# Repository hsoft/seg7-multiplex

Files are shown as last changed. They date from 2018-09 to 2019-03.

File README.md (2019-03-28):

# Multiplexed 7-segment display array

This board is a multiplexed array of 4 7-segment displays that receives its
input through a custom serial protocol. The board uses a USB-A connector to
connect `VCC`, `GND` and its two serial pins. It's multiplexed to minimize the
number of pins and ICs we need to use. We end up only needing an ATtiny45 and
2 ICs to drive the 4 displays.

The goal is to be able to offload the "digit display" complexity off little
devices I'm planning to do. Of course, there's tons of ready-to-use displays
out there but I'd like to explore simple and minimal designs.

I'm also hoping to have something that draws minimal current. My current
prototype (v3) works on 3V and draws about 7mA when it's not receiving data. For
reference, the backlight of a typical 2x8 LCD screen draws something like
20-40mA.

Click on the image below for a video:

vimeo (https://vimeo.com/327108521)

## Serial protocol

It works by serially sending it 5 bits of data using `INSER` and `INCLK`, the
first 4 bits being an encoded digit from `0` to `9`. Each digit is sent
starting with the most significant bit. Before each digit, a single bit is sent
to indicate whether this digit has a dot. The first digit to be sent is the
least significant digit (the rightmost).

Before that, a single "empty" clock is sent to "wake" the MCU up and give it
time to put itself in "input" mode (that is, give it time to finish its current
refresh operation, if any).

The driver should wait 200us before the "wake up" trigger and the rest of the
data so that we have time to finish any ongoing display refresh operation.
after that, 50us between each clock should be enough.

Thus, to send "43.21", the bits to be sent would be:

    00100 (4)
    10011 (dot + 3)
    00010 (2)
    00001 (1)
    01010 (10, the checksum of 4 + 3 + 2 + 1)

This is done for each digit that needs to be shown (starting with the rightmost
digit). This means 20 bits.

Following that, we have a checksum which is the sum, in binary form, of the
sent digits. That sum is 5 bits long. It's not enough to hold the maximum value
(36) of that sum, but being 5 bits simplifies the code and is solid enough for
our purpose. Dot masks aren't checksummed.

If the checksum doesn't match the received number, the display shows an error
that can't be mistaken for a real number.

I could have gone for sending straight binary values instead of digits but I
thought it would be nice to eventually add support for special values (dash,
empty, etc)

The board itself takes care of properly refreshing the displays. We refresh one
display every 1ms, cycling over active displays. We only need to send new digits
when they change.

## Prototypes

### v1

My first prototype was using two shift registers to multiplex my 7-segments
digits. It worked rather well but my craftmanship was lacking. Soldering wasn't
good and the board was too cramped. I also forgot (or didn't know about) to add
decoupling capacitors next to my ICs and I think that this is why that prototype
wasn't working perfectly (it would receive the wrong data through serial and
would even sometimes have a corrupt display (missing/extra segment) about 10% of
the time). Also, to get that figure to 10% from 50%, I had to lower my serial
clock timing to 100us (a minimum of 100us between serial clocks). That seems a
bit high to me. Something is fishy.

As a software developer, I'm used to be on solid grounds. If the code is
logical, generally, things work. Here I have to learn to deal with timing and
power fluctuation issues. These present interesting challenges.

Because my board was too cramped, I needed to make a new prototype altogether
(with decoupling capacitors this time) and I thought that if I was going to do
that, I might as well try another design, that is, my v2.

You can see the code for this v1 in the `v1` branch of this repo. I have no
KiCAD schema though. Never bothered. Will do for v2 though.

### v2

Although I think that my design for v1 was globally sound, I think in
retrospective that the MCU did too many things. The less things the MCU does,
the more logic you offload to ICs, the more robust your design is going to be (I
think). After all, people designing ICs went through much more trouble to make
sure it worked well than I did for my prototype...

So that's why I went with a new multiplex design with 3 ICs:

1. 7-segment decoder hooked to my displays
2. binary counter hooked to the decoder
3. shift register hooked to displays' `VCC` (and `DP`)

With the decoder + counter, sending a particular digit mask to the display is
only a matter of clocking the counter, so it's only two pin changes. That is
much much less than the number of pins we have to change to send a particular
digit mask into a shift register.

I could use a decade counter to only cycle through the first 10 glyphs of my
decoder's 16, but as I looked as extra glyphs, I realized (I really wasn't sure
what they were supposed to be for initially) that they're probably optimized for
multiplexing, that is, that the 5 extra masks (last one is blank) are masks that
"fit" multiple digits. For example, the 11th mask is the lower half of `5` which
also fits 6 and 8.

Therefore, when cycling through masks, you can enable `VCC` not only for exact
digit matches but also partial matches and, in the end, you've refreshed your
multiplexed displays properly. I'm thinking that 1ms per cycle should be good
enough to keep us under the 10ms threshold (at which point the eye starts to see
a flicker) even if we cycle through 16 digit masks.

One problem though is that the 7-segments decoder doesn't handle `DP`, which I'd
like to support. This is why I'm thinking of bringing down (theoretical) digit
support from 8 to 4 and hook 4 pins of my shift register directly to my `DP`
pins. This way, I'll handle `DP` status completely outside of the multiplexing
process.

With the `ATtiny45`, I only have 3 free output pins (2 pins are used for serial
communication). That requires creativity to handle all my ICs with only 3 pins,
but I think I have a good idea:

1. pins 1 and 2 hooked to my shift register
2. pin 3 to my binary counter
3. pin 3 also hooked to my shift register's `OE` pin (output enable).

I need to control `OE` because there's always going to be a slight window of
time during which the decoder cycled and the shift register hasn't updated `VCC`
pin yet. If I let `OE` on, then my displays are going to have "ghost" branches.
The pin clocking the binary counter is going to be in position to enable `OE`
most of the time and right when we will toggle the binary counter clock, `OE`
will become disabled. Then, I'll update the shift register and toggle `OE` back
(which will not trigger a binary counter update since it takes a full on/off
cycle to trigger). I haven't looked yet whether I'm going to be needing an
inverter for this. If yes, I'll probably look for a shift register that allows
me to do that without an inverter (an extra IC just for this seem a bit much).

**Conclusion**: It went well! It was the first time I ordered a PCB from a
KiCAD design. Of course, I made some mistakes in it and a lot of cowboy
soldering was necessary to adjust, but in the end, I had a fully functional
prototype! Unlike v1, it received data properly and displayed it correctly!

However, I'm not done yet, I need a v3 because 3 ICs is too many: I'd like to
get this package in a 55mmx30mmx20mm enclosure. I'll need to go "double side"
and remove an IC.

### v3

With v3, I get rid of the counter. Instead of using 4 bits of the SR for DP,
I connect them to the BCD. Then, I connect SER to DP add a refresh "round"
especially for DP. This means that we generally have to keep SER high to avoid
falsely lighting DPs.

It still offloads most of the complexity to the BCD and gets rid of an IC.
Moreover, althrough I didn't experience it, I felt that the CNT approach was
flaky: the counter **had** to stay in sync with the MCU and the MCU had no way
to reset the counter to enforce syncing (not enough pins).

## Build

To build the software, you need:

* [AVRA][avra]
* [avrdude][avrdude] to send firmware to MCUs

You can build the resulting `seg7multiplex.S.hex` with `make` and send it to
the MCU through `avrdude` with `make send`.

## Simulation

This project can be run on a desktop computer through [simavr][simavr]. It 
produces a VCD file which can then be opened with [gtkwave][gtkwave].

You can compile the simulation with `make simulation` and then run the
resulting executable without parameters.

The simulation runs two MCUs at the same time. First, of course, the
`seg7multiplex` program, but also, on a separate virtual attiny45, the `drive`
program. It hooks them up together and let them run for 2 seconds.

The resulting gtkwave file is very insightful for debugging.

[avra]: http://avra.sourceforge.net/
[avrdude]: https://www.nongnu.org/avrdude/
[simavr]: https://github.com/buserror/simavr
[gtkwave]: http://gtkwave.sourceforge.net/

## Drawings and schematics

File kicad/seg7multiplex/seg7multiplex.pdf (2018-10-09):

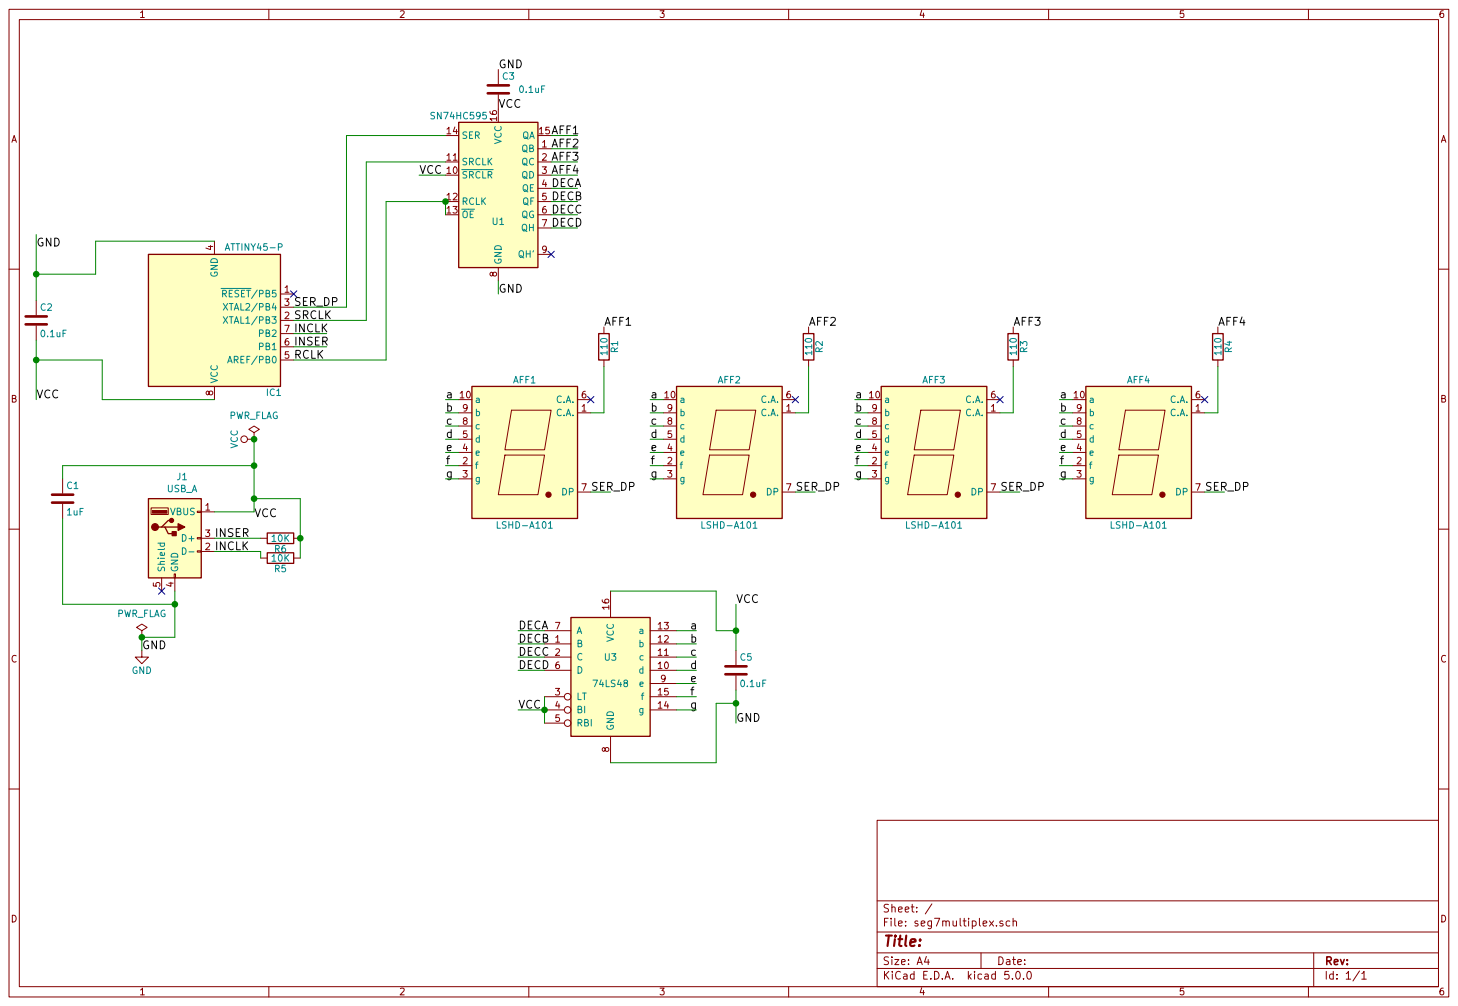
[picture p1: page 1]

INCLK
INSER

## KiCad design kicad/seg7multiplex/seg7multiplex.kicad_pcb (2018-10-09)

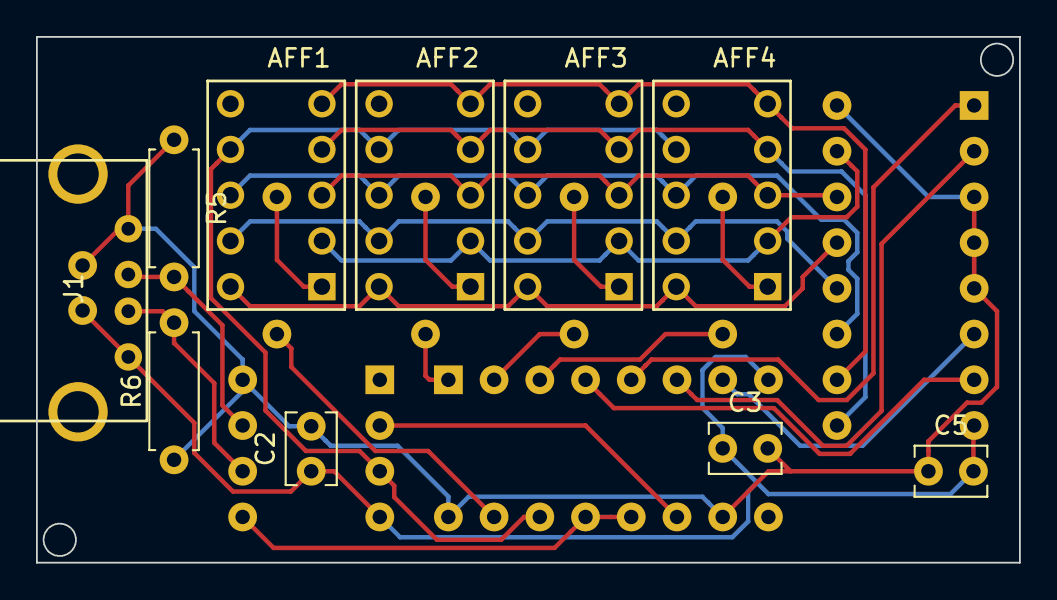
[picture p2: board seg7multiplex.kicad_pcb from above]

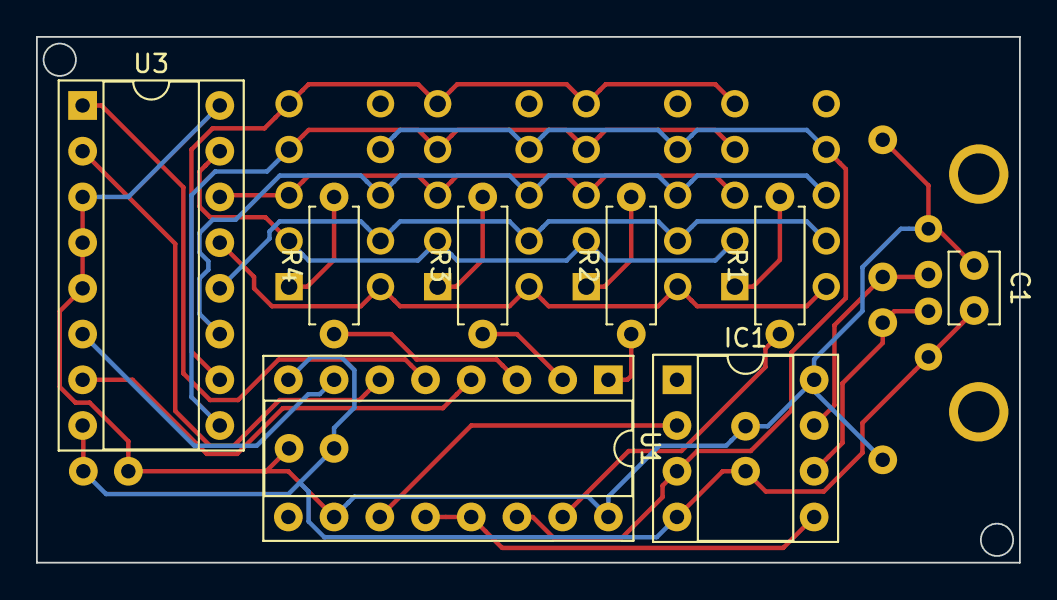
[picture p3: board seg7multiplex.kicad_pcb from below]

Board: 2 copper layers, 54.6 x 29.2 mm, 18 parts (8 on the bottom side), 26 nets.

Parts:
AFF1, AFF2, AFF3, AFF4: LSHD-A101
C1: 1uF; C_Disc_D3.8mm_W2.6mm_P2.50mm
C2, C3, C5: 0.1uF; C_Disc_D3.8mm_W2.6mm_P2.50mm
IC1: ATTINY45-P; DIP-8_W7.62mm_Socket
J1: USB_A; USB_A_Through
R1, R2, R3, R4: 110; R_Axial_DIN0207_L6.3mm_D2.5mm_P7.62mm_Horizontal
R5, R6: 10K; R_Axial_DIN0207_L6.3mm_D2.5mm_P7.62mm_Horizontal
U1: SN74HC595; DIP-16_W7.62mm_Socket
U3: 74LS48; DIP-16_W7.62mm_Socket

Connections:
/AFF1: R1.1, U1.15
/AFF2: R2.1, U1.1
/AFF3: R3.1, U1.2
/AFF4: R4.1, U1.3
/DECA: U1.4, U3.7
/DECB: U1.5, U3.1
/DECC: U1.6, U3.2
/DECD: U1.7, U3.6
/INCLK: IC1.7, J1.2, R5.2
/INSER: IC1.6, J1.3, R6.2
/RCLK: IC1.5, U1.12, U1.13
/SER_DP: AFF1.7, AFF2.7, AFF3.7, AFF4.7, IC1.3, U1.14
/SRCLK: IC1.2, U1.11
/a: AFF1.10, AFF2.10, AFF3.10, AFF4.10, U3.13
/b: AFF1.9, AFF2.9, AFF3.9, AFF4.9, U3.12
/c: AFF1.8, AFF2.8, AFF3.8, AFF4.8, U3.11
/d: AFF1.5, AFF2.5, AFF3.5, AFF4.5, U3.10
/e: AFF1.4, AFF2.4, AFF3.4, AFF4.4, U3.9
/f: AFF1.2, AFF2.2, AFF3.2, AFF4.2, U3.15
/g: AFF1.3, AFF2.3, AFF3.3, AFF4.3, U3.14
GND: C1.2, C2.1, C3.1, C5.2, IC1.4, J1.4, U1.8, U3.8
unnamed: AFF1.1, R1.2
unnamed: AFF2.1, R2.2
unnamed: AFF3.1, R3.2
unnamed: AFF4.1, R4.2
VCC: C1.1, C2.2, C3.2, C5.1, IC1.8, J1.1, R5.1, R6.1, U1.10, U1.16, U3.3, U3.4, U3.5, U3.16

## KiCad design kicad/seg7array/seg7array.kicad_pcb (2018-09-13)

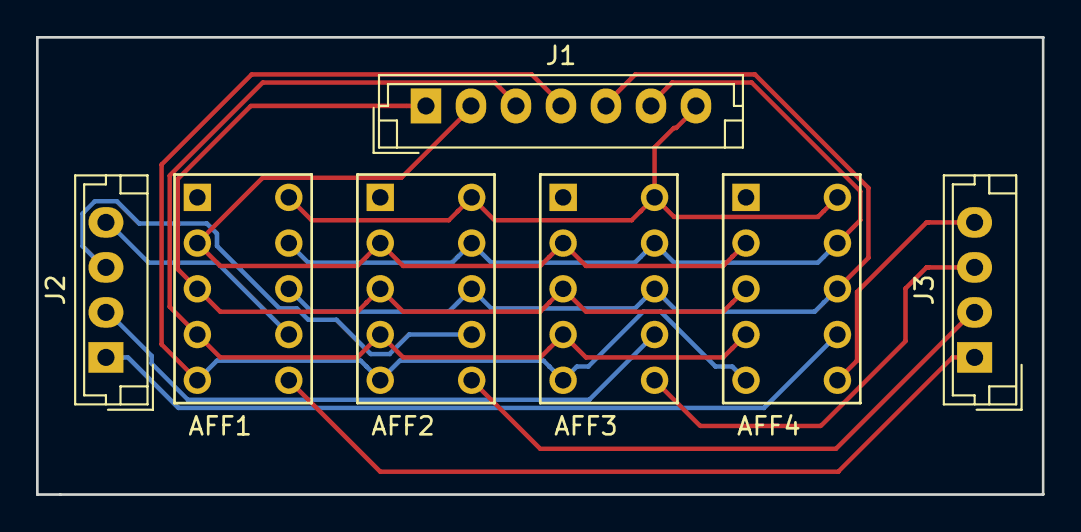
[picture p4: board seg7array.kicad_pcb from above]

Board: 2 copper layers, 55.9 x 25.4 mm, 7 parts (0 on the bottom side), 15 nets.

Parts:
AFF1, AFF2, AFF3, AFF4: LSHD-A101
J1: Conn_01x07; JST_EH_B07B-EH-A_1x07_P2.50mm_Vertical
J2, J3: Conn_01x04; JST_EH_B04B-EH-A_1x04_P2.50mm_Vertical

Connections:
/a: AFF1.10, AFF2.10, AFF3.10, AFF4.10, J1.7
/b: AFF1.9, AFF2.9, AFF3.9, AFF4.9, J1.6
/c: AFF1.8, AFF2.8, AFF3.8, AFF4.8, J1.5
/d: AFF1.5, AFF2.5, AFF3.5, AFF4.5, J1.4
/e: AFF1.4, AFF2.4, AFF3.4, AFF4.4, J1.3
/f: AFF1.2, AFF2.2, AFF3.2, AFF4.2, J1.2
/g: AFF1.3, AFF2.3, AFF3.3, AFF4.3, J1.1
unnamed: AFF1.6, J3.1
unnamed: AFF1.7, J2.4
unnamed: AFF2.6, J3.2
unnamed: AFF2.7, J2.3
unnamed: AFF3.6, J3.3
unnamed: AFF3.7, J2.2
unnamed: AFF4.6, J3.4
unnamed: AFF4.7, J2.1

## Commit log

2017-09-22 Fix glitches in seg7 simulation display
    It now works pretty well with our two displays. The only "glitch" we can
    see sometimes is the leftover of the previous digit when increasing our
    value, but that's to be expected because that's how the LED fading logic
    works.
2017-09-22 Add a 3rd digit through a decoder and inverter
    For a reason I haven't yet figured out, when we hit the `300` value, the
    LED display goes to `044`. strange...
2017-09-26 Stop using PB5
    Will I ever learn that this pin cannot be used as IO? To free that pin,
    I've made the `SER` pin shared between inputs and outputs. Works in
    simulation...
2017-10-24 Fix inverted B2 and B3 pins
    The wiring of the prototype wasn't the same as in the simulation. But as
    of now, we know that the "display" part of code works on the prototype (it
    has, however, only 3 digits)! The serial input hasn't been tested yet.
2017-10-30 sim: extract SerialInput from Circuit
    Also, use new `enable_interrupt_on_pin()` MCU method.
2017-11-04 Adapt code so it works with my new prototype
    I've scrapped my old prototype to make a new one that fits in a small
    box. The way wiring is done in this new prototype requires that I change
    my code.
    Also, add a new `--ftdi` option to the simulator!
2017-11-08 Big refactoring: make display refreshing routine more atomic
    My serial input routine was too heavy for its own good and I had to
    rethink the whole process. See comment in seg7multiplex.c
    This works in simulation, haven't tried on my prototype yet.
2017-11-10 Still trying to make things work
    My previous approach didn't work on the prototype, `SER` still got
    confused all the time. Now instead of having a fine-grained "lock" on
    `SER`'s input/output mode, I'm trying a more coarse-grained approach
    with `input_mode`.
    Here, we begin each serial session with a single "empty" `INCLK` rising
    edge that tells the MCU to stop all display refreshing activity. The MCU
    then sets `SER` to input mode as soon as it can in the runloop.
    On the other side of the serial wire, we have to wait a bit to make sure
    we're good to go, and then go ahead with or 20 bits (for 4 digits) of
    data.
    After that, the `input_mode` flag goes back to `false` and normal
    operations resu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
2017-11-10 Give INSER its own pin
    The idea of sharing the `SER` pin with `INSER` was a bad idea. It might
    be possible to make it work, but its over my current skill level.
    `SR1`'s `RCLK` had its own pin, so I took it out and hard-wired it to
    `SRCLK`. That makes the seg7 output code a bit uglier, but it frees a
    pin.
    This works on the prototype! finally!
    There are some occasional glitches though, but they're much much less
    frequent than ever before. I'll have to iron them out though...
2017-11-30 sim: extract circuit in a separate unit
    This will make integration in other projects easier.
2017-12-07 Add FTDI support to drive serial input of the real prototype!
    And it works! I have a functional prototype!
2018-03-15 Planning out v2 of my prototype
2018-03-19 Add KiCAD schema
    [seg7multiplex.sch]
2018-03-25 Update code and simulation to the v2 prototype
    Once a couple of kinks in `icemu` were fixed, works surprisely well,
    with serial input code untouched and all.
    `DP` is not implemented yet.
2018-09-07 Update to Kicad 5
    [seg7multiplex.sch]
2018-09-07 Try to associate some footprints to components
    [seg7multiplex.sch]
2018-09-08 Add USB connector to schema and generate netlist
    [seg7multiplex.sch]
2018-09-13 Add new kicad "seg7array" project
    [seg7array.kicad_pcb, seg7array.sch, seg7multiplex.sch]
2018-09-18 kicad: add seg7multiplex footprint
    [seg7multiplex.kicad_pcb, seg7multiplex.sch]
2018-10-08 Adjustment after first prototype revision
    I've received my first KiCAD-designed PCB! After a few cowboy adjustments
    (soldering stuff here and there), I could manage to make the thing work!
    But it flickered badly, so I had to heavily optimize my multiplexing
    algo to make flickering go away. As it is right now, and with
    modification to my KiCAD design (which have been done manually on my
    PCB to confirm soundness), I get a display that displays stuff correctly
    without flickering!
    I have yet to test the serial input. That's the next step before I send
    a second revision of the PCB to the fab.
    Exciting stuff!
    [seg7multiplex.kicad_pcb, seg7multiplex.sch]
2018-10-08 It works perfectly!!!
    After some sizeable messing around, I could finally make the prototype
    work perfrectly! I mean: the serial protocol works without a hitch, the
    proper digits get there 100% of the time! No flickering!
    One time cnosuming problem I had was that my FT232H controller I use
    for testing has a 5V power supply, but 3V logic (it outputs 3V to its
    data pins). It took me a while to realise that. Things weren't working
    at all.
    To make the prototype compatible with 3V logic, I transformed the
    pulldown resistors for INCLK and INSER into pull-up resistor so that the
    signal is brought a bit further from the 2.5V threshold between HIGH and
    LOW (it brings signal from 2.4V previously to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
    [seg7multiplex.kicad_pcb, seg7multiplex.sch]
2018-10-24 Reverse digits
    Bullseye! I received my PCB for this 3rd prototype, I solder it, power
    it up, it works perfectly on the first try! No flickering, displaying
    what it should... Except that the digits were reversed.
    I haven't tried USB communication yet though...
    So now I have this tight PCB that almost fits (U3 it too close to the
    screw socket, it doesn't fit quite right. But it's no big deal, I have
    wiggle room to move the IC a little bit away) in my small enclosure.
2019-01-15 Reverse digits (again)
    It seems that I've turned my displays around without noticing in my
    latest prototype.
    But otherwise, I now have a prototype that work very well! It properly
    receives input from FTDI, doesn't flicker and the board didn't need any
    modification!
    The only problem is that the board is a *tiny bit* too large on a corner
    to fit in my enclosure. I could cut the corner, but there's an IC there.
    There's enough place on the board to move it a bit, so I'll do that.
    But first, I need to test the communication protocol when it originates
    from another MCU (instead of a FTDI device).
2019-01-31 Merge digit_count into current_digit
    Since they're never used in the same mode, we can save one precious
    byte!
2019-01-31 Add checksum digit to communication protocol
    My prototype was sometimes (but rarely), receiving the wrong number. I'm
    not sure if it's due to bad soldering in my USB wire or voltage
    irregularities or whatever else, but if I'm going to use those readings
    for anything important, I have to be able to trust the the number
    displayed is the good one.
2019-02-20 sim: bring in the driver!
    First steps into allowing the simulation of a seg7 driver at the same
    time as the seg7 itself.
2019-02-22 Use AVRA for compiling instead of avr-gcc
    I like AVRA better than binutils's `avr-as` because it's simpler, more
    self-contained, and also, it tries to mimick `avrasm`, which allows me
    to write assembler code that is more in line with what a majority of
    other AVR users write.
2019-02-23 Implement input mode in assembler
    Works well in simulation for the first sent digit group (2345). It
    seems that subsequent digit groups trigger error condition. To examine.
    But otherwise, I'm still really happy with how simavr/gtkwave debugging
    works out. Very easy to debug tricky situations.
    My eyes are getting used to decode binary out of two CLK/SER tracks :)
2019-02-23 Fix checksum sent in wrong order by the driver
2019-02-24 Rewrite driver in asm
